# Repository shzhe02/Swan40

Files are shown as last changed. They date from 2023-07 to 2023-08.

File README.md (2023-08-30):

# Swan40 - A 40-key split keyboard.

My first attempt at designing a custom sleek split keyboard.

Heavily inspired by the [Corne](https://github.com/foostan/crkbd) and [Ferris Sweep](https://github.com/davidphilipbarr/Sweep).

More extensive write-up (in progress): https://shzhe02.com/projects/swan40

The provided ZMK config is essentially:
- 80% [Corne default zmk config and keymap](https://github.com/zmkfirmware/zmk/tree/main/app/boards/shields/corne)
- 10% [Pnohty config for the Ferris Sweep](https://github.com/rayduck/zmk-config)
- 10% Manual configuration for the Swan40

Features:
- Uses the XIAO nRF528420 microcontroller
- Up to 1000 mAh lipo battery without tenting (with 102050 lipo)
- Dual-orientation lipo mounting
- On-off switch hard wired to battery
- Should be compatible with Choc v1 and v2 switches (only v1 tested)
- Hotswap switches
- Plate-mounted switches

BOM:
- 2x XIAO nRF52840 (compatible with both non-sense or sense versions)
- 2x MSK-12C02 switches
- 40x Kailh Low-profile hotswap sockets
- 40x 1N4148W T4 SOD123 diodes
- Some jumper wires (for connecting the battery pads on the PCB to the battery pads on the microcontroller)
- Electrical tape (place over battery-connected pads on PCB after soldering to reduce chances of a short-circuit occuring)
- 40x Kailh Choc v1/v2 switches
- 40x MBK keycaps (or compatible keycaps of your choice)
- (Optional) 2x MBK homing keycaps (In this case, only 38 normal keycaps are needed)

Optional (but recommended) case: https://www.printables.com/model/561315-swan40-case

Case BOM:
- 3x M2 (OD 3.2mm) x 4mm brass inserts
- 3x M2 x 5mm screws (preferrably button head torx (or hex))
- 2x M2 x 10mm screws

Wiring notes:
- Positive and negative battery terminals should be soldered to the BAT+ and BAT- pads on the PCB respectively.
- The BOARD+ and BOARD- pads on the PCB should be soldered to jumper wires connecting them to the BAT+ and BAT- pads on the microcontroller respectively.
- I recommend first connecting the microcontroller to the PCB and using a multimeter to ensure that the switch works and there are no shorts between the BAT+ and BAT- pads of the PCB before connecting the battery.
- When soldering the battery to the PCB, I recommend doing the following:
  - Tape off the end of one of the battery wires with some sort of insulating tape (I used masking tape).
  - Route the taped wire through the battery wire hole on the PCB (check the write up for more details) followed by the other wire.
  - Solder the non-taped wire to its corresponding battery pad on the PCB.
  - After the pad has cooled down, place some insulating tape over the entire pad but leave the other pad exposed.
  - Un-tape the taped wire and solder it to the other battery pad on the PCB.
  - Remove the tape on the other pad, and cover both pads with electrical tape.

Potential future improvements:
- [ ] Make main PCB reversible
- [ ] Change lipo connection SMD pads to an SMD micro JST 1.25 connector
- [ ] Figure out a safer (more foolproof) method to connect battery pads of the controller to the PCB.
- [ ] Design a smaller battery cover for the 500 mAh 602035 lipo

Credits:
- [foostan's kbd KiCad Library/Symbols/3D Models](https://github.com/foostan/kbd/tree/crkbd4)
    - Located in the directory: pcb/assets/kbd, plate/assets/kbd, left-plate/assets/kbd, and right-plate/assets/kbd
- [Seeed Studio XIAO nRF52840 STEP model - by Maurice Pannard](https://grabcad.com/library/seeed-studio-xiao-nrf52840-sense-1)
    - Located in the directory: pcb/assets/xiao_nrf52840
- [Kailh 1350 Socket (Choc V1 Hotswap sockets) STEP model - by Dennis Lee](https://grabcad.com/library/kailh-1350-socket-2)
    - Located in the directory: pcb/assets/kailh_choc_v1_hotswap
- [MBK Choc Low Profile 1u keycap STEP model - by darryldh](https://www.thingiverse.com/thing:4564253)
    - Located in the directory: pcb/assets/kailh_choc_v1_hotswap
- [MSK-12C02 SMD Slider Switch Footprint - by mzst](https://mzstblog.blogspot.com/2016/01/msk-12c02-smd-slider-switch-spdt-eagle.html)
    - Located in the directory: pcb/assets/MSK-12C02
- Rayduck and Foostan for the ZMK config

Note: Modifications were made to many of the assets.

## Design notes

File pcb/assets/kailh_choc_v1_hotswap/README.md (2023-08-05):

Original source of the socket STEP file: https://grabcad.com/library/kailh-1350-socket-2
Original source of the keycap STEP flie: https://www.thingiverse.com/thing:4564253/files

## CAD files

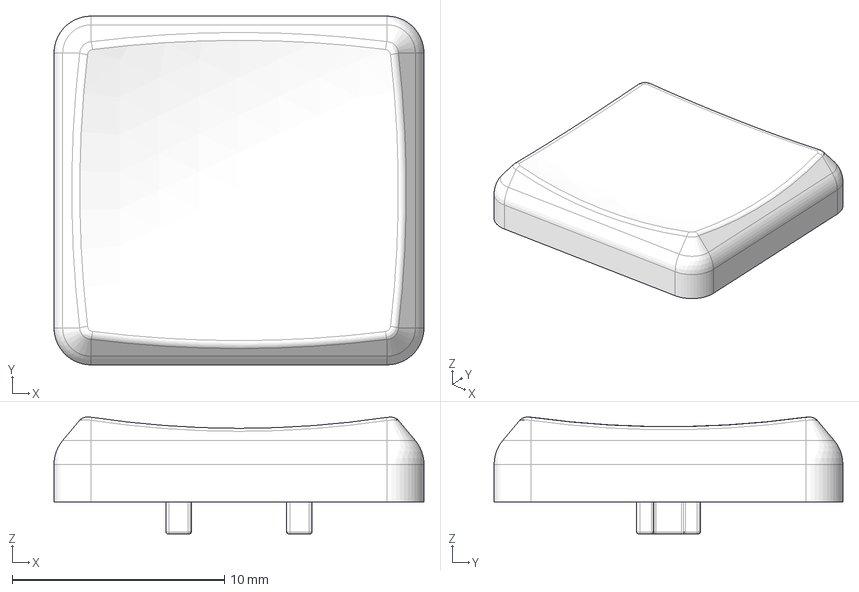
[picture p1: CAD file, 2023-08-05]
pcb/assets/kailh_choc_v1_hotswap/MBK_Keycap_-_1u.step
17.4 x 16.4 x 5.52 mm

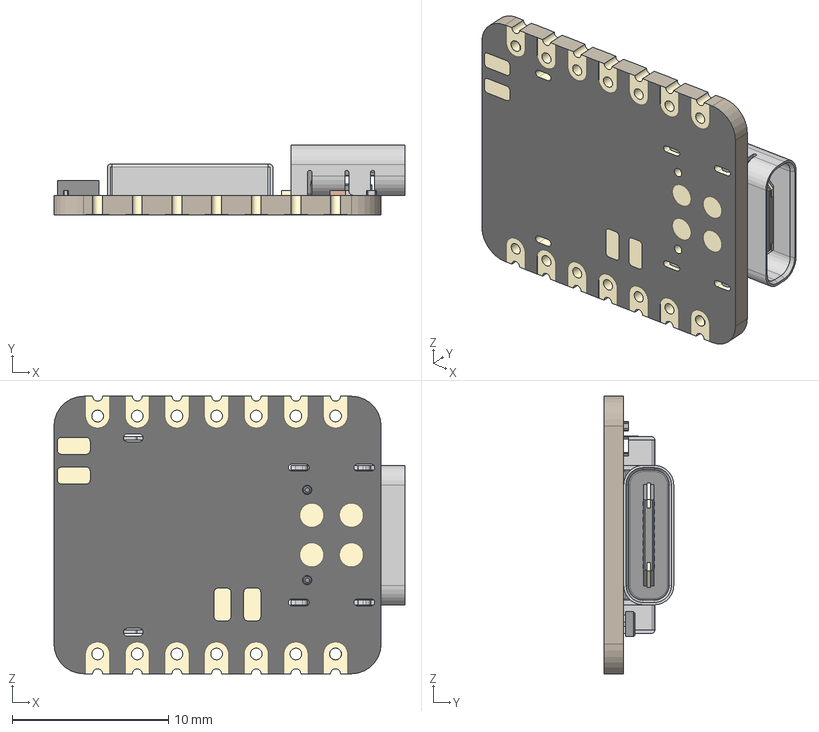
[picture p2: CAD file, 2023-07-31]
pcb/assets/xiao_nrf52840/XIAO-nRF52840 v15.step
22.5 x 4.46 x 17.8 mm
BOSS-EXTRUDE14_8_
BOSS-EXTRUDE7_4_
BOSS-EXTRUDE7_3_
BOSS-EXTRUDE14_4_
BOSS-EXTRUDE14_2_
BOSS-EXTRUDE14_11_
BOSS-EXTRUDE7_7_
BOSS-EXTRUDE14_9_
BOSS-EXTRUDE14_3_
BOSS-EXTRUDE14_7_
MIRROR2
BOSS-EXTRUDE14_5_
BOSS-EXTRUDE14_12_
BOSS-EXTRUDE7_8_
BOSS-EXTRUDE7_1_
BOSS-EXTRUDE14_10_
BOSS-EXTRUDE7_9_
BOSS-EXTRUDE14_6_
BOSS-EXTRUDE14_1_
BOSS-EXTRUDE7_6_
BOSS-EXTRUDE7_2_
CUT-EXTRUDE5
BOSS-EXTRUDE7_5_
Shield
Pins
CAP x 2
ANT1
Silkscreen
CAP 3
LED
USR
2 v1

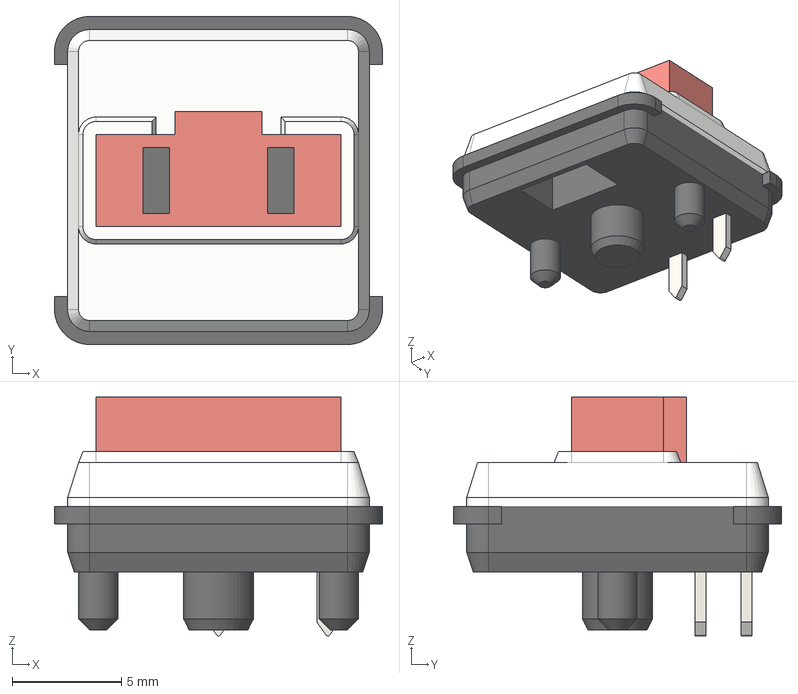
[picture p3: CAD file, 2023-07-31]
pcb/assets/kailh_choc_v1_hotswap/kailh_choc.step
15.0 x 15.0 x 10.9 mm

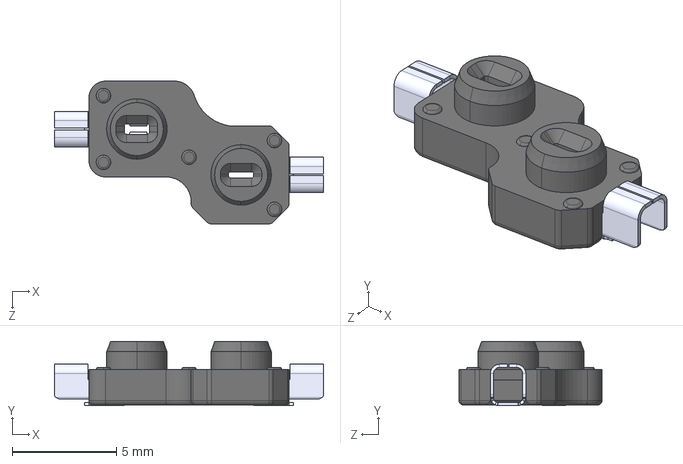
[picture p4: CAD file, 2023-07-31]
pcb/assets/kailh_choc_v1_hotswap/PG1350-socket.STEP
12.9 x 3.09 x 6.85 mm
pin x 2
socket

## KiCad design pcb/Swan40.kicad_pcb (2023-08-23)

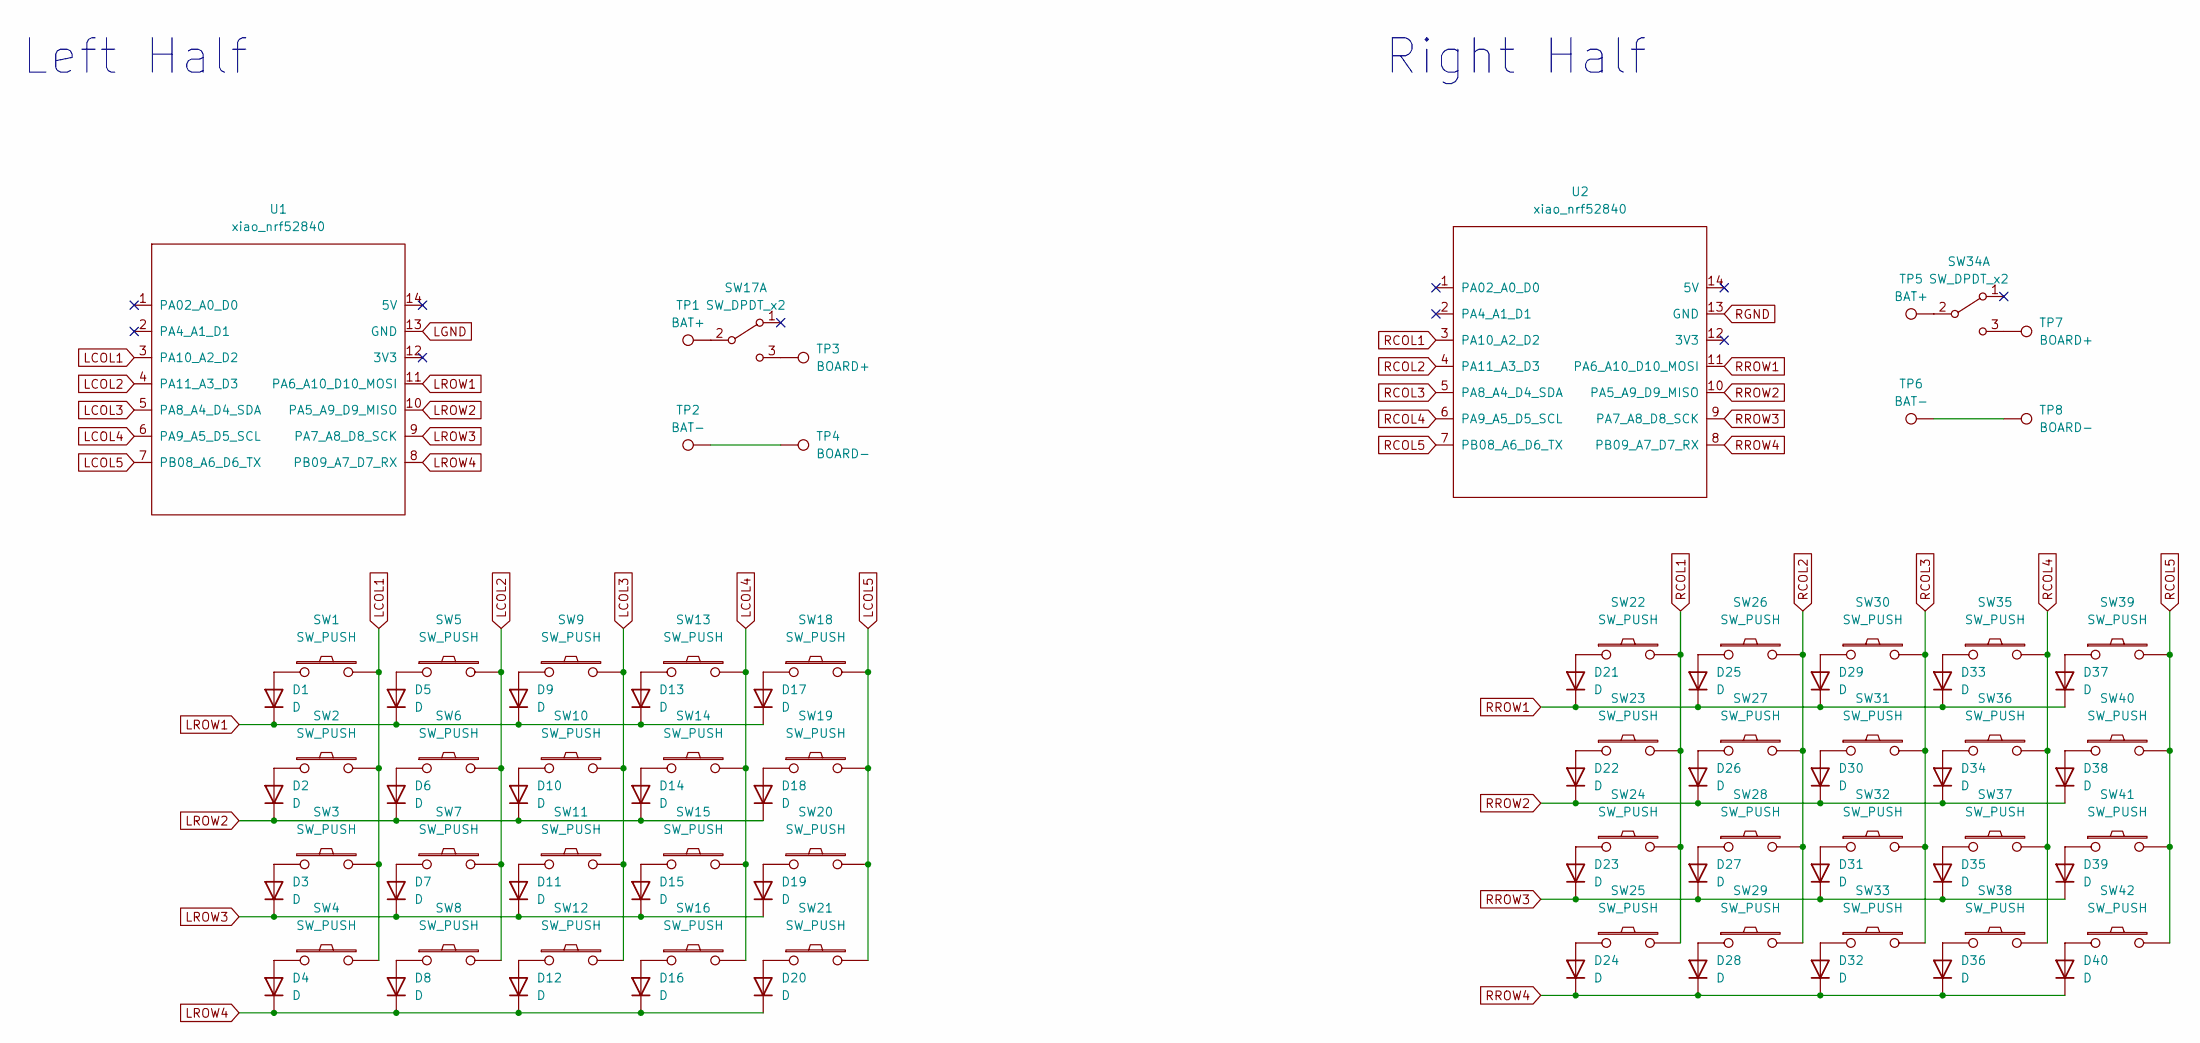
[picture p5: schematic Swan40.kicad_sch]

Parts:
D1, D2, D3, D4, D5, D6, D7, D8, D9, D10, D11, D12, D13, D14, D15, D16, D17, D18, D19, D20, D21, D22, D23, D24, D25, D26, D27, D28, D29, D30, D31, D32, D33, D34, D35, D36, D37, D38, D39, D40: D; D3_SMD_v2
SW1, SW2, SW3, SW4, SW5, SW6, SW7, SW8, SW9, SW10, SW11, SW12, SW13, SW14, SW15, SW16, SW18, SW19, SW20, SW21, SW22, SW23, SW24, SW25, SW26, SW27, SW28, SW29, SW30, SW31, SW32, SW33, SW35, SW36, SW37, SW38, SW39, SW40, SW41, SW42: SW_PUSH; ChocV1_V2_Hotswap
SW17, SW34: SW_DPDT_x2; MSK-12C02
TP1, TP5: BAT+; 1pad_conn_board
TP2, TP6: BAT-; 1pad_conn_board
TP3, TP7: BOARD+; 1pad_conn_board
TP4, TP8: BOARD-; 1pad_conn_board
U1, U2: xiao_nrf52840; xiao_nrf52840_v2

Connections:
LCOL1: SW1.2, SW2.2, SW3.2, SW4.2, U1.3 (PA10_A2_D2)
LCOL2: SW5.2, SW6.2, SW7.2, SW8.2, U1.4 (PA11_A3_D3)
LCOL3: SW9.2, SW10.2, SW11.2, SW12.2, U1.5 (PA8_A4_D4_SDA)
LCOL4: SW13.2, SW14.2, SW15.2, SW16.2, U1.6 (PA9_A5_D5_SCL)
LCOL5: SW18.2, SW19.2, SW20.2, SW21.2, U1.7 (PB08_A6_D6_TX)
LGND: U1.13 (GND)
LROW1: D1.1 (K), D5.1 (K), D9.1 (K), D13.1 (K), D17.1 (K), U1.11 (PA6_A10_D10_MOSI)
LROW2: D2.1 (K), D6.1 (K), D10.1 (K), D14.1 (K), D18.1 (K), U1.10 (PA5_A9_D9_MISO)
LROW3: D3.1 (K), D7.1 (K), D11.1 (K), D15.1 (K), D19.1 (K), U1.9 (PA7_A8_D8_SCK)
LROW4: D4.1 (K), D8.1 (K), D12.1 (K), D16.1 (K), D20.1 (K), U1.8 (PB09_A7_D7_RX)
unnamed: D1.2 (A), SW1.1
unnamed: D2.2 (A), SW2.1
unnamed: D3.2 (A), SW3.1
unnamed: D4.2 (A), SW4.1
unnamed: D5.2 (A), SW5.1
unnamed: D6.2 (A), SW6.1
unnamed: D7.2 (A), SW7.1
unnamed: D8.2 (A), SW8.1
unnamed: D9.2 (A), SW9.1
unnamed: D10.2 (A), SW10.1
unnamed: D11.2 (A), SW11.1
unnamed: D12.2 (A), SW12.1
unnamed: D13.2 (A), SW13.1
unnamed: D14.2 (A), SW14.1
unnamed: D15.2 (A), SW15.1
unnamed: D16.2 (A), SW16.1
unnamed: D17.2 (A), SW18.1
unnamed: D18.2 (A), SW19.1
unnamed: D19.2 (A), SW20.1
unnamed: D20.2 (A), SW21.1
unnamed: D21.2 (A), SW22.1
unnamed: D22.2 (A), SW23.1
unnamed: D23.2 (A), SW24.1
unnamed: D24.2 (A), SW25.1
unnamed: D25.2 (A), SW26.1
unnamed: D26.2 (A), SW27.1
unnamed: D27.2 (A), SW28.1
unnamed: D28.2 (A), SW29.1
unnamed: D29.2 (A), SW30.1
unnamed: D30.2 (A), SW31.1
unnamed: D31.2 (A), SW32.1
unnamed: D32.2 (A), SW33.1
unnamed: D33.2 (A), SW35.1
unnamed: D34.2 (A), SW36.1
unnamed: D35.2 (A), SW37.1
unnamed: D36.2 (A), SW38.1
unnamed: D37.2 (A), SW39.1
unnamed: D38.2 (A), SW40.1
unnamed: D39.2 (A), SW41.1
unnamed: D40.2 (A), SW42.1
unnamed 50: SW17.2 (B), TP1.1; also elsewhere on the board
unnamed 51: SW17.3 (C), TP3.1; also elsewhere on the board
unnamed 52: SW34.2 (B), TP5.1; also elsewhere on the board
unnamed 53: SW34.3 (C), TP7.1; also elsewhere on the board
unnamed 54: TP2.1, TP4.1; also elsewhere on the board
unnamed 55: TP6.1, TP8.1; also elsewhere on the board
RCOL1: SW22.2, SW23.2, SW24.2, SW25.2, U2.3 (PA10_A2_D2)
RCOL2: SW26.2, SW27.2, SW28.2, SW29.2, U2.4 (PA11_A3_D3)
RCOL3: SW30.2, SW31.2, SW32.2, SW33.2, U2.5 (PA8_A4_D4_SDA)
RCOL4: SW35.2, SW36.2, SW37.2, SW38.2, U2.6 (PA9_A5_D5_SCL)
RCOL5: SW39.2, SW40.2, SW41.2, SW42.2, U2.7 (PB08_A6_D6_TX)
RGND: U2.13 (GND)
RROW1: D21.1 (K), D25.1 (K), D29.1 (K), D33.1 (K), D37.1 (K), U2.11 (PA6_A10_D10_MOSI)
RROW2: D22.1 (K), D26.1 (K), D30.1 (K), D34.1 (K), D38.1 (K), U2.10 (PA5_A9_D9_MISO)
RROW3: D23.1 (K), D27.1 (K), D31.1 (K), D35.1 (K), D39.1 (K), U2.9 (PA7_A8_D8_SCK)
RROW4: D24.1 (K), D28.1 (K), D32.1 (K), D36.1 (K), D40.1 (K), U2.8 (PB09_A7_D7_RX)

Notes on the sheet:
Right Half
Left Half

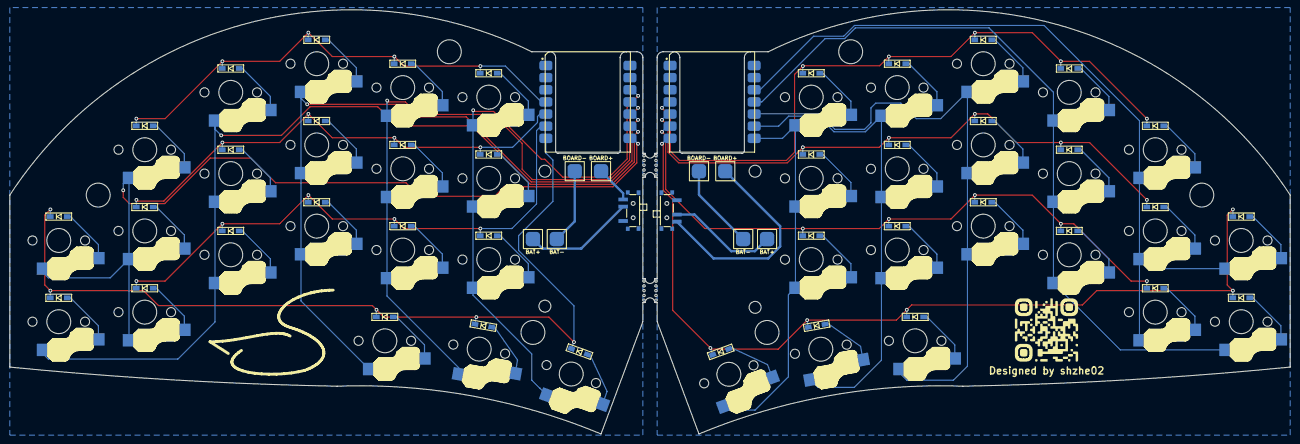
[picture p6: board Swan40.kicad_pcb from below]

Board: 2 copper layers, 268.0 x 88.8 mm, 92 parts (52 on the bottom side), 64 nets.

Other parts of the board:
BAT+: BAT+; 1pad_conn_board
BAT+#2: BAT+; 1pad_conn_board
BAT-: BAT-; 1pad_conn_board
BAT-#2: BAT-; 1pad_conn_board
BOARD+: BOARD+; 1pad_conn_board
BOARD+#2: BOARD+; 1pad_conn_board
BOARD-: BOARD-; 1pad_conn_board
BOARD-#2: BOARD-; 1pad_conn_board

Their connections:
unnamed 50: BAT+#2.1; also elsewhere on the board
unnamed 51: BOARD+.1; also elsewhere on the board
unnamed 52: BAT+.1; also elsewhere on the board
unnamed 53: BOARD+#2.1; also elsewhere on the board
unnamed 54: BAT-#2.1, BOARD-.1; also elsewhere on the board
unnamed 55: BAT-.1, BOARD-#2.1; also elsewhere on the board

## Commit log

2023-08-05 Semi-broken 1st attempt
    [MBK_Keycap_-_1u.step, Swan40.kicad_sch, kailh_choc.step]
2023-08-11 Designed + Export automation (#1)
    * Base wiring completed
    * Updated board outline
    * Wiring complete
    * Fixed errors + Rounded tracks
    * Rounded + added droplets + fill zones
    * Added base kibot automation
    * Fixed workflow
    * Attempted fix
    * Switched to rounded file
    * Attempted fix
    * Fixed typo
    * Updated readme
    * Runs action every time
    * Everything re-aligned and re-wired
    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
    [Swan40-rounded.kicad_pcb, Swan40.kicad_sch]
2023-08-12 Refactored + Polished (#2)
    * Refactored folders, added plates
    * Fixed typo in workflows
    * Fixed config import
    * Combined all workflows
    * Renamed jobs
    * Added reversable plate
    * Editted footprint
    * Updated unrounded PCB with silkscreens + updated workflow
    [MBK_Keycap_-_1u.step, PG1350-socket.STEP, Swan40-rounded.kicad_pcb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]
2023-08-23 added documentation
    [Swan40.kicad_pcb]
